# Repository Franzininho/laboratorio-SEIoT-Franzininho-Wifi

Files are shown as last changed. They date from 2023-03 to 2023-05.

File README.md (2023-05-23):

## Laboratório de Sistemas Embarcados e IoT - Franzininho Wifi

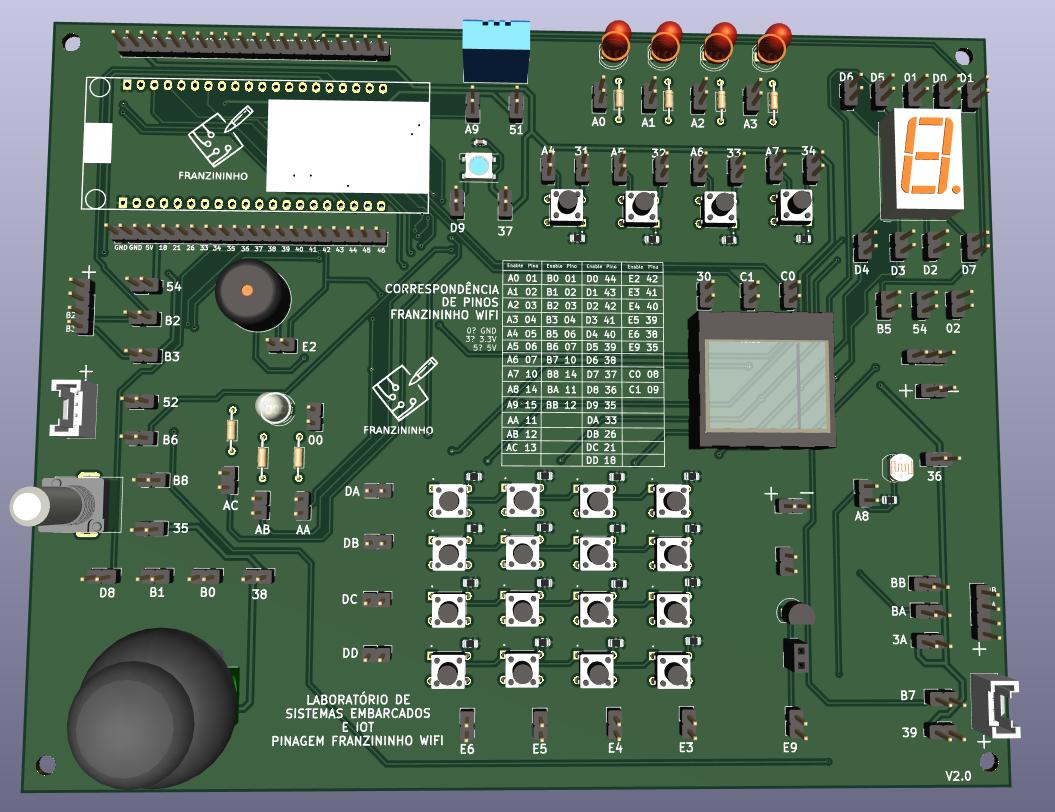
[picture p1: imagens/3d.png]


## O que é este projeto?

O projeto **Laboratório de Sistemas Embarcados e IoT** é um projeto de placa de circuito impresso para facilitar o uso de componentes eletrônicos em oficinas de programação. Este projeto possui um socket para conexão da placa [Franzininho Wifi](https://github.com/Franzininho/Franzininho-WiFi) e diversos periféricos conectados à pinos pré-determinados do socket que podem ser ativados utilizando um conector jumper ou mais.

Esse projeto tem o intuito de auxiliar no ensino de programação utilizando placas microcontroladas já que muitas vezes nas oficinas de programação com placas microcontroladas é despendido muito tempo para lidar com problemas que vem da manipulação do hardware como utilização da protoabord e realização de conexões. Este tempo muitas vezes acaba prejudicando a atividade já que o tempo onde se foca em fazer as conexões eletrônicas poderia ser melhor aproveitado focando na programação realmente.

Sendo assim, utilizando a facilidade de conexão de periféricos da placa é possível reduzir drásticamente o tempo despendido para conexões eletrônicas, focando no objetivo da oficina, que é a programação.

Esse projeto está sob a licença [CERN-OHL-S v2](https://ohwr.org/cern_ohl_s_v2.txt)

## Como ativar os periféricos?

Os periféricos utilizados na placa são ativados através de pinos de ativação. Esses pinos são compostos por dois pinos macho que devem ser conectados. Um desses pinos macho está conectado ao socket da placa e o outro a um pino do componente eletrônico. Dessa forma, o jumper fecha a conexão entre o componente e a placa microcontrolada. Uma exemplo desse tipo de conexão está evidenciado na figura abaixo pelas linhas verdes:

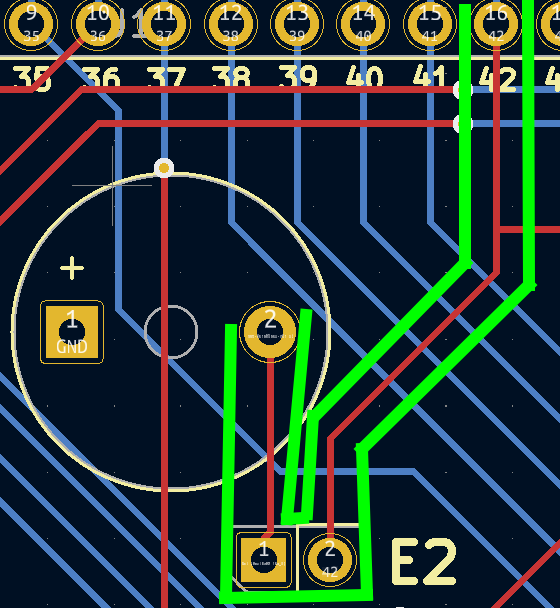
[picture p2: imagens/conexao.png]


Como "ativador" para os pinos, recomendo o uso do conector da imagem abaixo. Você pode encontrar esse conector como "jumper com aba", "mini jumper com aba", "jumper cap", entre outros.

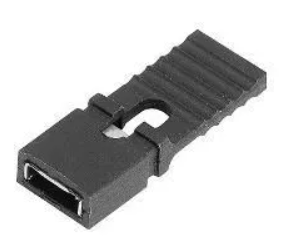
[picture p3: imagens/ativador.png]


Além dos pinos de ativação de sinal que conectam o componente ao socket da placa, existem também os pinos de ativação de energia que são responsáveis por energizar o componente.

## Codificação dos pinos de ativação

Devido à quantidade de pinos de ativação usada na placa, foi preciso desenvolver um sistema de codificação para esses pinos. Esse sistema foi idealizado com cada pino sendo representado por dois algarismos. O primeiro indicando a funcionalidade do pino e o segundo indicando uma numeração do pino. As funções dos primeiros algarismos podem ser vistas abaixo:

| Letra | Significado |
| :---: | :---: |
| 0 | GND |
| 3 | VCC 3.3V |
| 5 | VCC 5V |
| A | Pinos analógicos |
| B | Pinos conectados em um mesmo pino identificado por A |
| C | Especiais |
| D | Pinos digitais |
| E | Pinos conectados em um mesmo pino identificado por D |

O código correspondente a cada pino de ativação foi impresso ao lado desse pino e o mapeamento dos pinos de ativação para os pinos da placa Franzininho Wifi está impresso na placa e também pode ser acessado [clicando aqui](./informacoes/mapeamento.md). Além disso, também foi desenvolvida uma biblioteca para uso em conjunto com a placa que permite o uso dos códigos dos pinos de ativação dentro da programação. [Clique aqui para acessar a **biblioteca laboratorioFW**](https://github.com/Franzininho/biblioteca-laboratorioFW)

A lista dos periféricos disponíveis e dos pinos de ativação necessários para ativar esses periféricos pode ser acessadas [clicando aqui](./informacoes/ativacao-perifericos.md). É importante lembrar que além dos periféricos a placa também conta com conectores para sensores e atuadores externos no formato de pinos macho e de conectores Grove.

## Como o projeto foi desenvolvido?

O projeto foi desenvolvido com o software [KiCad 7](https://www.kicad.org/). Esse software é aberto e está disponível para Linux, MacOS e Windows.

## Adaptadores

Buscando aumentar ainda mais a versatilidade do projeto, estão sendo desenvolvidos adaptadores para a placa que permitem a conexão dela com outras placas microcontroladas.

### Placas adaptadoras desenvolvidas até o momento:

-   [Arduino Uno](https://github.com/Franzininho/laboratorio-SEIoT-adaptador-arduino)

## Certificação OSHWA
(https://certification.oshwa.org/br000014.html)

[Clique aqui](https://certification.oshwa.org/br000014.html) para acessar
---

#### Feito por [LelePG](https://github.com/LelePG)

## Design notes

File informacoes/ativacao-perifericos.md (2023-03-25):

| Periferico | Pinos de Ativação | Código na imagem |
| :---: | :---: | :---: |
| LEDs difusos | A0,A1,A2,A3 (dependendo do LED escolhido) | 1 |
| Botões | A4,A5,A6,A7 (dependendo do botão escolhido) | 7 |
| Buzzer | E2 | 6 |
| LED RGB | AC,AB,AA,00 | 12 |
| Potenciômetro | B8,35 | 5 |
| Sensor de luminosidade | A8,36 | 10 |
| Sensor de umidade e temperatura DTH11 | A9, 51 | 14 |
| Display de 7 segmentos | D0,D1,D2,D3,D4,D5,D6,D7, 01 | 8 |
| Transistor NPN | E9 | 9 |
| Display OLED | C0,C1,30 | 2 |
| Teclado Matricial | DA,DB,DC,DD,E6,E4,E3 | 3 |
| Conexão para Servo Motor | B5,54,02 | 11 |
| LED RGB endereçável | D9,37 | 13 |
| Módulo Joystick | D8,B1,B0,38 | 4 |
| Conectores fêmea de 4 pinos | (BA,BB,3A) ou (B3,B2,54) dependendo do conector escolhido | 17 e 15 |
| Conectores Grove | (B7, 39) OU (52, B6) dependendo do conector escolhido | 16 e 18 |

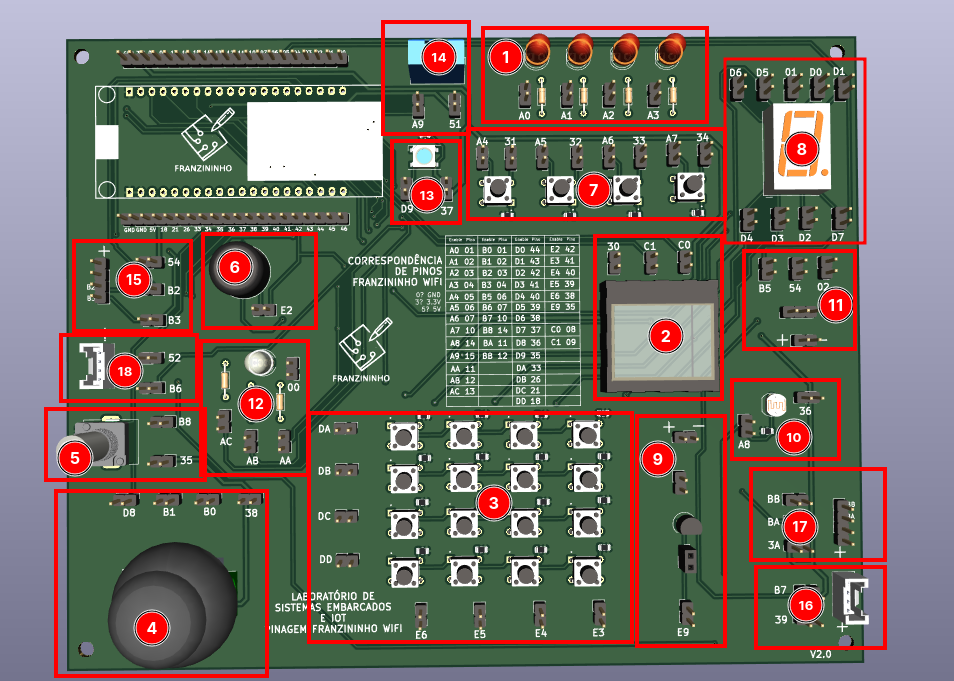
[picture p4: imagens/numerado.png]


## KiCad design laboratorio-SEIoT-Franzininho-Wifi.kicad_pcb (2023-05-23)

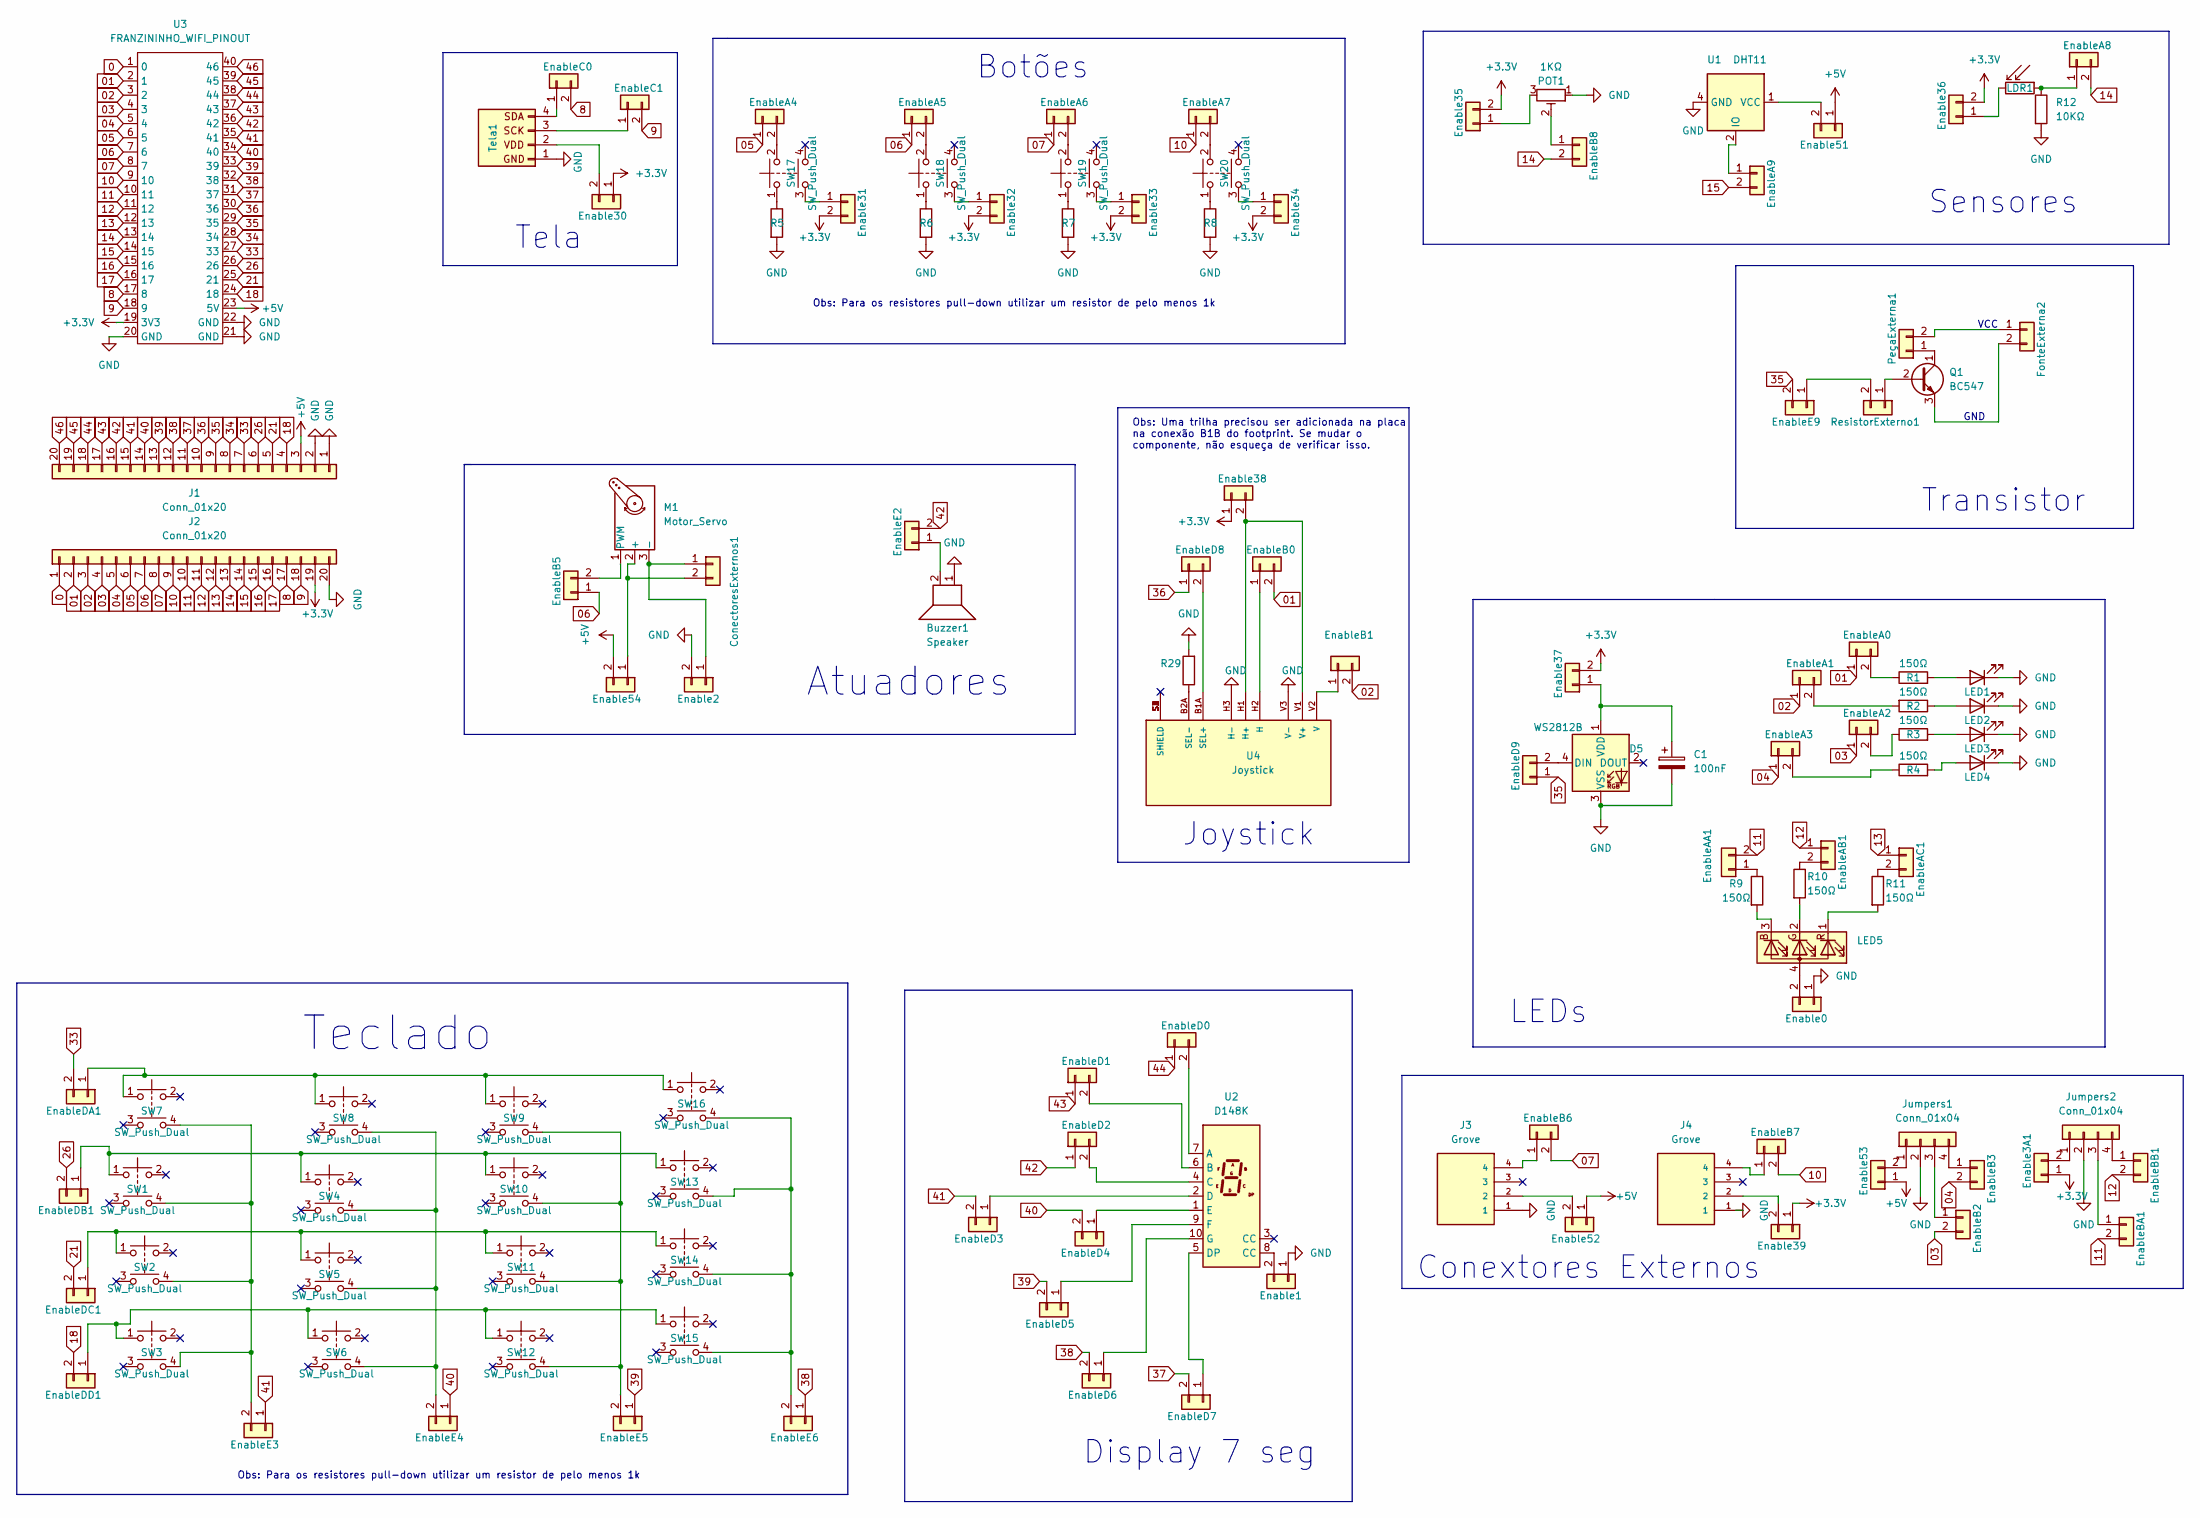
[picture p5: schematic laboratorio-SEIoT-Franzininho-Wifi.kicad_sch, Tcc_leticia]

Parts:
Buzzer1: Speaker; Buzzer_12x9.5RM7.6
C1: 100nF; C_0603_1608Metric
ConectoresExternos1: Conn_01x02; PinHeader_1x02_P2.54mm_Vertical
D1: LED1; LED_D5.0mm
D2: LED2; LED_D5.0mm
D3: LED3; LED_D5.0mm
D4: LED4; LED_D5.0mm
D5: WS2812B; LED_WS2812B_PLCC4_5.0x5.0mm_P3.2mm
Enable0, Enable1, Enable2, Enable3A1, Enable30, Enable31, Enable32, Enable33, Enable34, Enable35, Enable36, Enable37, Enable38, Enable39, Enable51, Enable52, Enable53, Enable54: Conn_01x02; PinHeader_1x02_P2.54mm_Vertical
EnableA0, EnableA1, EnableA2, EnableA3, EnableA4, EnableA5, EnableA6, EnableA7, EnableA8, EnableA9: Conn_01x02; PinHeader_1x02_P2.54mm_Vertical
EnableAA1: Conn_01x02; PinHeader_1x02_P2.54mm_Vertical
EnableAB1: Conn_01x02; PinHeader_1x02_P2.54mm_Vertical
EnableAC1: Conn_01x02; PinHeader_1x02_P2.54mm_Vertical
EnableB0, EnableB1, EnableB2, EnableB3, EnableB5, EnableB6, EnableB7, EnableB8: Conn_01x02; PinHeader_1x02_P2.54mm_Vertical
EnableBA1: Conn_01x02; PinHeader_1x02_P2.54mm_Vertical
EnableBB1: Conn_01x02; PinHeader_1x02_P2.54mm_Vertical
EnableC0, EnableC1: Conn_01x02; PinHeader_1x02_P2.54mm_Vertical
EnableD0, EnableD1, EnableD2, EnableD3, EnableD4, EnableD5, EnableD6, EnableD7, EnableD8, EnableD9: Conn_01x02; PinHeader_1x02_P2.54mm_Vertical
EnableDA1: Conn_01x02; PinHeader_1x02_P2.54mm_Vertical
EnableDB1: Conn_01x02; PinHeader_1x02_P2.54mm_Vertical
EnableDC1: Conn_01x02; PinHeader_1x02_P2.54mm_Vertical
EnableDD1: Conn_01x02; PinHeader_1x02_P2.54mm_Vertical
EnableE2, EnableE3, EnableE4, EnableE5, EnableE6, EnableE9: Conn_01x02; PinHeader_1x02_P2.54mm_Vertical
FonteExterna2: Conn_01x02; PinHeader_1x02_P2.54mm_Vertical
J1, J2: Conn_01x20; PinHeader_1x20_P2.54mm_Vertical
J3, J4: Grove; PARTREV A
Jumpers1, Jumpers2: Conn_01x04; PinHeader_1x04_P2.54mm_Vertical
LDR1: LDR07; R_LDR_5.1x4.3mm_P3.4mm_Vertical
LED5: LED_RGBA; LED_D5.0mm-4_RGB
M1: Motor_Servo; PinHeader_1x03_P2.54mm_Vertical
POT1: 1KΩ; Potentiometer_Alps_RK09K_Single_Vertical
PeçaExterna1: Conn_01x02; PinHeader_1x02_P2.54mm_Vertical
Q1: BC547; TO-92_Inline
R1, R2, R3, R4, R9, R10, R11: 150Ω; R_Axial_DIN0204_L3.6mm_D1.6mm_P7.62mm_Horizontal
R5, R6, R7, R8: 150Ω; R_0805_2012Metric
R12: 10KΩ; R_0805_2012Metric
R29: R; R_0805_2012Metric
ResistorExterno1: Conn_01x02; PinSocket_1x02_P2.54mm_Vertical
SW1, SW2, SW3, SW4, SW5, SW6, SW7, SW8, SW9, SW10, SW11, SW12, SW13, SW14, SW15, SW16, SW17, SW18, SW19, SW20: SW_Push_Dual; Switch
Tela1: Conn_01x04; PinHeader_1x04_P2.54mm_Vertical
U1: DHT11; Aosong_DHT11_5.5x12.0_P2.54mm
U2: D148K; D1X8K
U3: FRANZININHO_WIFI_PINOUT
U4: Joystick; PARTREV N/A

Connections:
0: J2.1, U3.1 (0)
01: EnableA0.1, EnableB0.2, J2.2, U3.2 (1)
02: EnableA1.1, EnableB1.2, J2.3, U3.3 (2)
03: EnableA2.1, EnableB2.2, J2.4, U3.4 (3)
04: EnableA3.1, EnableB3.2, J2.5, U3.5 (4)
05: EnableA4.1, J2.6, U3.6 (5)
06: EnableA5.1, EnableB5.1, J2.7, U3.7 (6)
07: EnableA6.1, EnableB6.2, J2.8, U3.8 (7)
8: EnableC0.2, J2.17, U3.17 (8)
9: EnableC1.2, J2.18, U3.18 (9)
10: EnableA7.1, EnableB7.2, J2.9, U3.9 (10)
11: EnableAA1.2, EnableBA1.2, J2.10, U3.10 (11)
12: EnableAB1.1, EnableBB1.2, J2.11, U3.11 (12)
13: EnableAC1.1, J2.12, U3.12 (13)
14: EnableA8.2, EnableB8.2, J2.13, U3.13 (14)
15: EnableA9.2, J2.14, U3.14 (15)
16: J2.15, U3.15 (16)
17: J2.16, U3.16 (17)
18: EnableDD1.2, J1.4, U3.24 (18)
21: EnableDC1.2, J1.5, U3.25 (21)
26: EnableDB1.2, J1.6, U3.26
33: EnableDA1.2, J1.7, U3.27 (33)
34: J1.8, U3.28 (34)
35: EnableD9.1, EnableE9.2, J1.9, U3.29 (35)
36: EnableD8.1, J1.10, U3.30 (36)
37: EnableD7.2, J1.11, U3.31 (37)
38: EnableD6.2, EnableE6.1, J1.12, U3.32 (38)
39: EnableD5.2, EnableE5.1, J1.13, U3.33 (39)
40: EnableD4.2, EnableE4.1, J1.14, U3.34 (40)
41: EnableD3.2, EnableE3.1, J1.15, U3.35 (41)
42: EnableD2.1, EnableE2.2, J1.16, U3.36 (42)
43: EnableD1.1, J1.17, U3.37 (43)
44: EnableD0.1, J1.18, U3.38 (44)
45: J1.19, U3.39 (45)
46: J1.20, U3.40 (46)
+3.3V: Enable3A1.1, Enable30.1, Enable31.2, Enable32.2, Enable33.2, Enable34.2, Enable35.2, Enable36.2, Enable37.2, Enable38.1, Enable39.1, J2.19, U3.19 (3V3)
+5V: Enable51.1, Enable52.1, Enable53.1, Enable54.2, J1.3, U3.23 (5V)
GND: Buzzer1.1, C1.2, D1.1 (K), D2.1 (K), D3.1 (K), D4.1 (K), D5.3 (VSS), Enable0.1, Enable1.1, Enable2.2, J1.1, J1.2, J2.20, J3.1, J4.1, Jumpers1.2, Jumpers2.2, POT1.1, R5.2, R6.2, R7.2, R8.2, R12.2, R29.2, Tela1.1, U1.4 (GND), U3.20 (GND), U3.21 (GND), U3.22 (GND), U4.H3 (H-), U4.V3 (V-)
unnamed: ConectoresExternos1.1, Enable2.1, M1.3 (-)
unnamed: ConectoresExternos1.2, Enable54.1, M1.2 (+)
unnamed: D1.2 (A), R1.2
unnamed: D2.2 (A), R2.1
unnamed: D3.2 (A), R3.2
unnamed: D4.2 (A), R4.2
unnamed: D5.4 (DIN), EnableD9.2
unnamed: C1.1, D5.1 (VDD), Enable37.1
unnamed: Enable0.2, LED5.4 (A)
unnamed: Enable1.2, U2.8 (CC)
unnamed: Enable3A1.2, Jumpers2.1
unnamed: Enable30.2, Tela1.2
unnamed: Enable31.1, SW17.3
unnamed: Enable32.1, SW18.3
unnamed: Enable33.1, SW19.3
unnamed: Enable34.1, SW20.3
unnamed: Enable35.1, POT1.3
unnamed: Enable36.1, LDR1.2
unnamed: Enable38.2, U4.B2B, U4.H1 (H+), U4.V1 (V+)
unnamed: Enable39.2, J4.2
unnamed: Enable51.2, U1.1 (VCC)
unnamed: Enable52.2, J3.2
unnamed: Enable53.2, Jumpers1.1
unnamed: EnableA0.2, R1.1
unnamed: EnableA1.2, R2.2
unnamed: EnableA2.2, R3.1
unnamed: EnableA3.2, R4.1
unnamed: EnableA4.2, SW17.2
unnamed: EnableA5.2, SW18.2
unnamed: EnableA6.2, SW19.2
unnamed: EnableA7.2, SW20.2
unnamed: EnableA8.1, LDR1.1, R12.1
unnamed: EnableA9.1, U1.2 (IO)
unnamed: EnableAA1.1, R9.1
unnamed: EnableAB1.2, R10.1
unnamed: EnableAC1.2, R11.1
unnamed: EnableB0.1, U4.H2 (H)
unnamed: EnableB1.1, U4.V2 (V)
unnamed: EnableB2.1, Jumpers1.3
unnamed: EnableB3.1, Jumpers1.4
unnamed: EnableB5.2, M1.1 (PWM)
unnamed: EnableB6.1, J3.4
unnamed: EnableB7.1, J4.4
unnamed: EnableB8.1, POT1.2
unnamed: EnableBA1.1, Jumpers2.3
unnamed: EnableBB1.1, Jumpers2.4
unnamed: EnableC0.1, Tela1.4
unnamed: EnableC1.1, Tela1.3
unnamed: EnableD0.2, U2.7 (A)
unnamed: EnableD1.2, U2.6 (B)
unnamed: EnableD2.2, U2.4 (C)
unnamed: EnableD3.1, U2.2 (D)
unnamed: EnableD4.1, U2.1 (E)
unnamed: EnableD5.1, U2.9 (F)
unnamed: EnableD6.1, U2.10 (G)
unnamed: EnableD7.1, U2.5 (DP)
unnamed: EnableD8.2, U4.B1A (SEL+)
unnamed: EnableDA1.1, SW7.1, SW8.1, SW9.1, SW16.1
unnamed: EnableDB1.1, SW1.1, SW4.1, SW10.1, SW13.1
unnamed: EnableDC1.1, SW2.1, SW5.1, SW11.1, SW14.1
unnamed: EnableDD1.1, SW3.1, SW6.1, SW12.1, SW15.1
unnamed: Buzzer1.2, EnableE2.1
unnamed: EnableE3.2, SW1.4, SW2.4, SW3.4, SW7.4
unnamed: EnableE4.2, SW4.4, SW5.4, SW6.4, SW8.4
unnamed: EnableE5.2, SW9.4, SW10.4, SW11.4, SW12.4
unnamed: EnableE6.2, SW13.4, SW14.4, SW15.4, SW16.4
unnamed: EnableE9.1, ResistorExterno1.2
unnamed: FonteExterna2.1, PeçaExterna1.2
unnamed: FonteExterna2.2, Q1.3 (E)
unnamed: LED5.3 (BK), R9.2
unnamed: LED5.2 (GK), R10.2
unnamed: LED5.1 (RK), R11.2
unnamed: PeçaExterna1.1, Q1.1 (C)
unnamed: Q1.2 (B), ResistorExterno1.1
unnamed: R5.1, SW17.1
unnamed: R6.1, SW18.1
unnamed: R7.1, SW19.1
unnamed: R8.1, SW20.1
unnamed: R29.1, U4.B2A (SEL-)

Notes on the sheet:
Obs: Para os resistores pull-down utilizar um resistor de pelo menos 1k
Botões
Conextores Externos
GND
Display 7 seg
Obs: Uma trilha precisou ser adicionada na placa na conexão B1B do footprint. Se mudar o componente, não esqueça de verificar isso.
VCC
LEDs
Atuadores
Joystick
Teclado
Transistor
Sensores
Tela

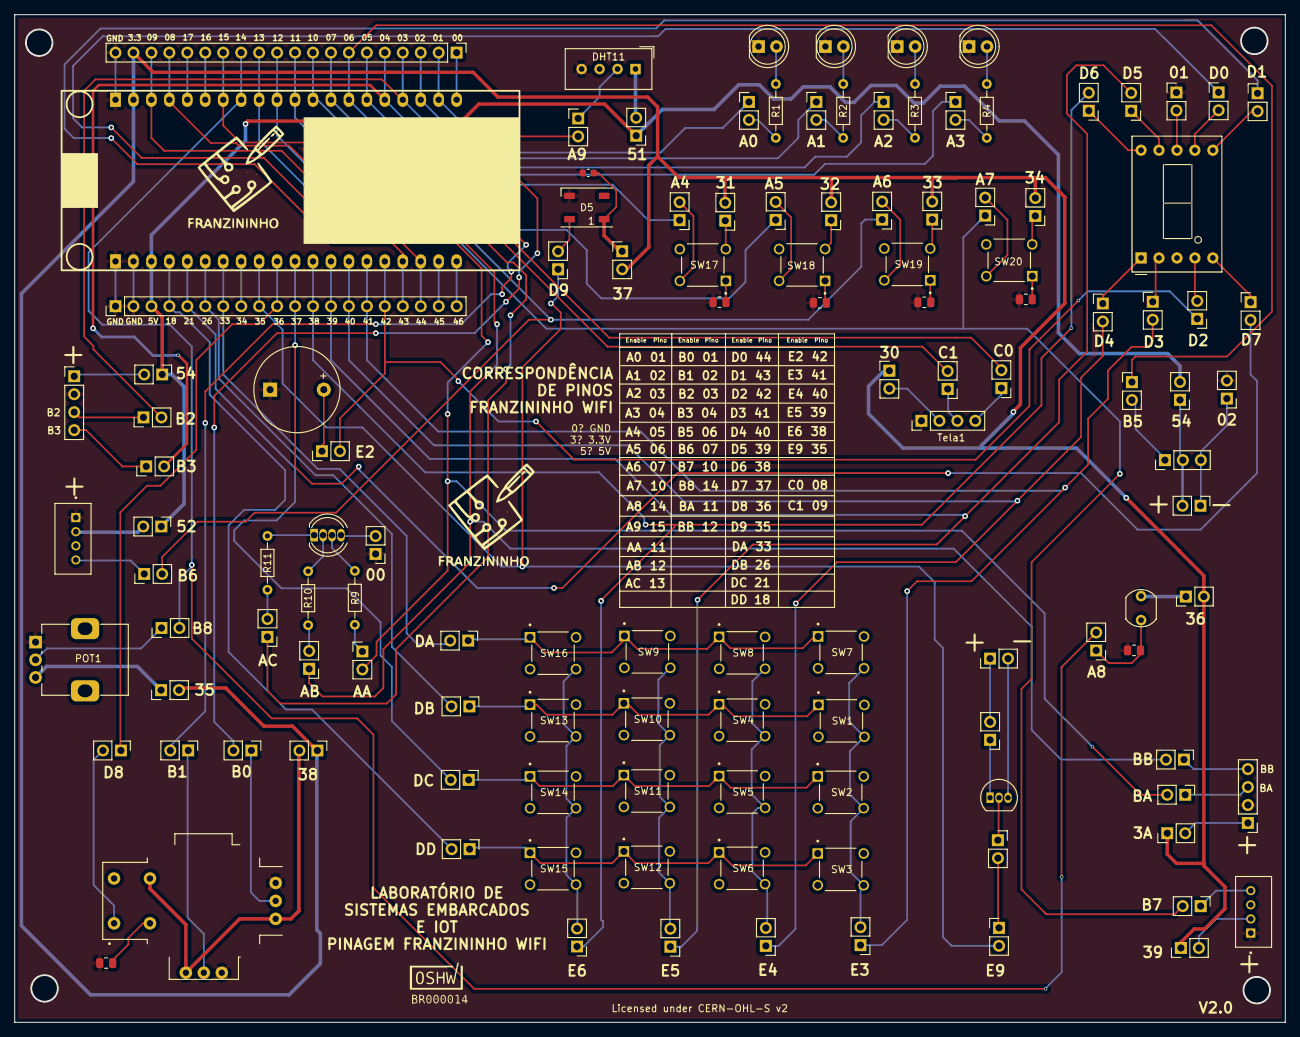
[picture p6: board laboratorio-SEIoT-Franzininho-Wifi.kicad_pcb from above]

Board: 2 copper layers, 179.8 x 142.6 mm, 124 parts (0 on the bottom side), 117 nets.

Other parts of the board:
G1: LOGO

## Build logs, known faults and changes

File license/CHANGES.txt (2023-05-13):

Change Format
Your name Date Description of modification

Change Log

Letícia Garcez 2023-05-12 Initial release of Laboratório de Sistemas Embarcados e IoT - Franzininho Wifi under cern_ohl_s_v2

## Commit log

2023-03-25 commit inicial
    [laboratorio-SEIoT-Franzininho-Wifi.kicad_pcb, laboratorio-SEIoT-Franzininho-Wifi.kicad_sch]
2023-03-27 correção de conexão no display de 7 segmentos
    [laboratorio-SEIoT-Franzininho-Wifi.kicad_pcb, laboratorio-SEIoT-Franzininho-Wifi.kicad_sch]
2023-05-13 adição da licensa
    [laboratorio-SEIoT-Franzininho-Wifi.kicad_pcb]
2023-05-23 certificação adicionada
    [laboratorio-SEIoT-Franzininho-Wifi.kicad_pcb]

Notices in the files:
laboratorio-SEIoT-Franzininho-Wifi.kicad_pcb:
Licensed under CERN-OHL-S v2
